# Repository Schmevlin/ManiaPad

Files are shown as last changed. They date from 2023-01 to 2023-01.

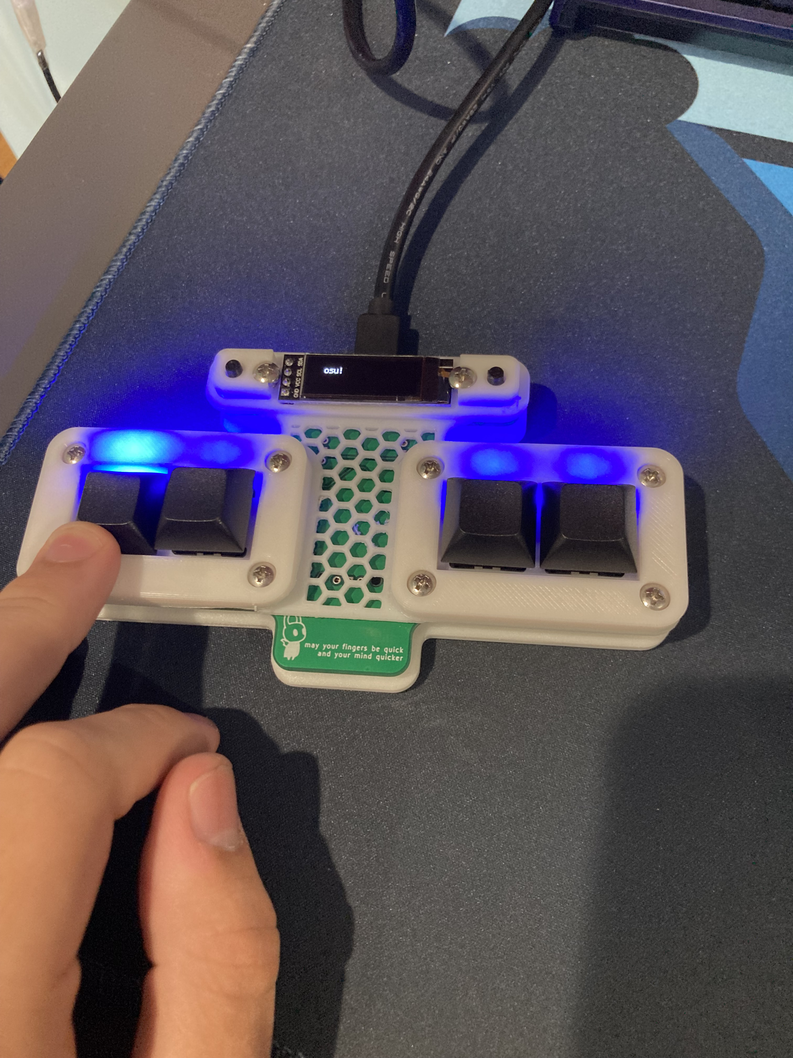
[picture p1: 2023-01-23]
pictures/IMG_0937.jpg

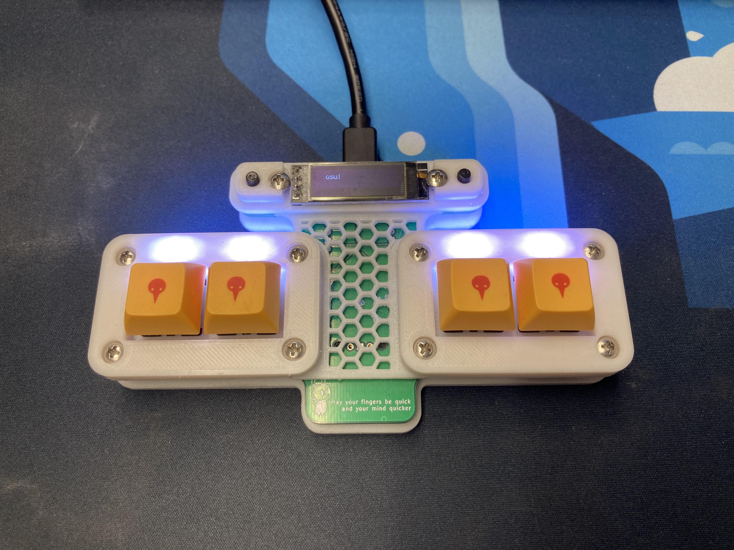
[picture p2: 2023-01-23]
pictures/IMG_2324.jpg

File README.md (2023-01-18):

# ManiaPad
4 button macro pad for use in rhythm games, primarily for osu!/osu!Mania

### Parts List
* pcb based on the one in this repo
* raspberry pi pico
* 0.91" I2C SSD 1306 OLED Module
* 1x4 pin header
* 4 individual WS2812B leds
* (optional) 4 100nF 1206 SMD capacitors
* 4 kailh hotswap sockets
* 4 cherry mx style mechanical keyboard switches
* 2 6mm x 6mm x 4.3mm tactile switch (push button)
* 10 M3 x 16mm machine screws
* 10 M3 nuts
* 3D Printed Parts
  * 4 plate spacer
  * 2 key block
  * 10 button spacer
  * 1 bottom
  * 6 short spacer
  * 1 middle plate
  * 2 button extender

### Button modes/layout
Button modes and layouts are in the code as the "modes" variable, with a tuples of (function name, string name). The functions define what buttons are pressed and what behaviour is associated with each mode. To swap modes hold the top left button then press the top right button.

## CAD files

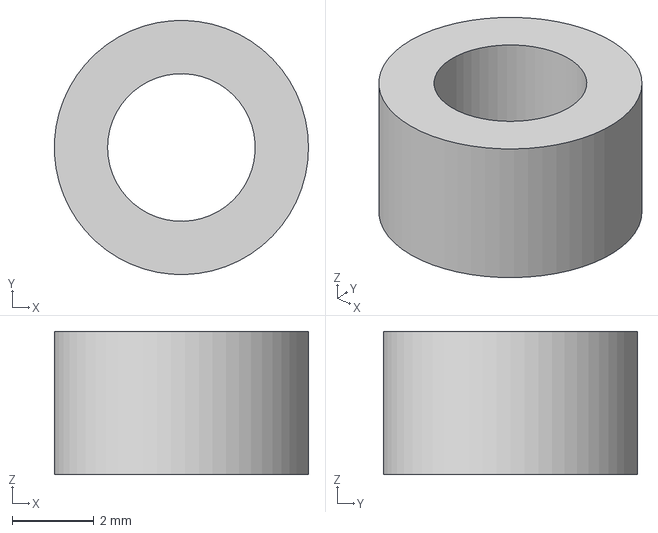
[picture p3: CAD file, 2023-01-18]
cad/plate-spacer.step
6.20 x 6.20 x 3.50 mm

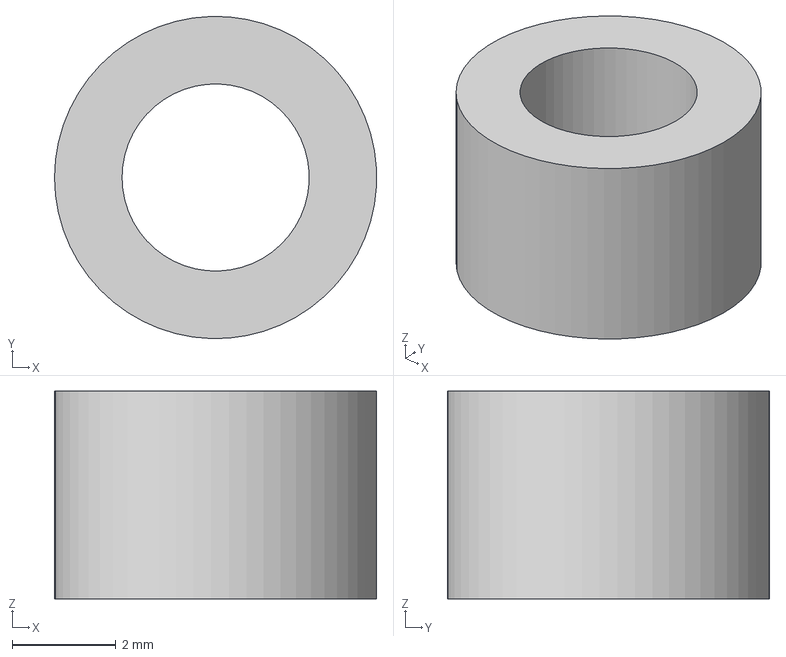
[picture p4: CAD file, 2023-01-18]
cad/bottom-spacer.step
6.20 x 6.20 x 4.00 mm

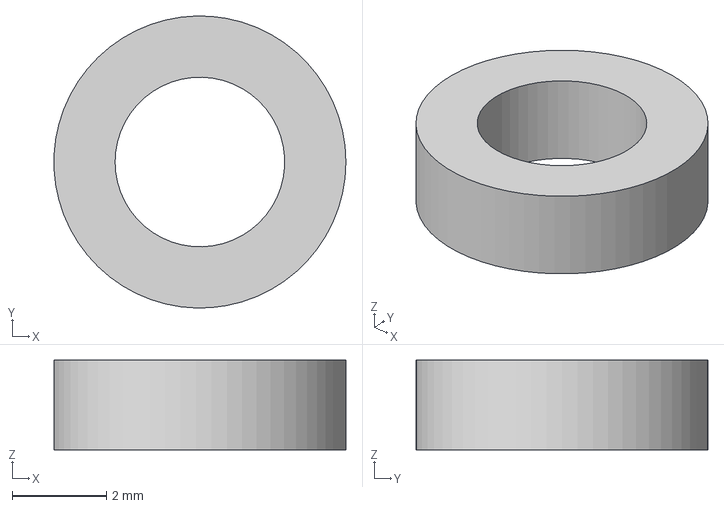
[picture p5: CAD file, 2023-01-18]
cad/short-spacer.step
6.20 x 6.20 x 1.90 mm

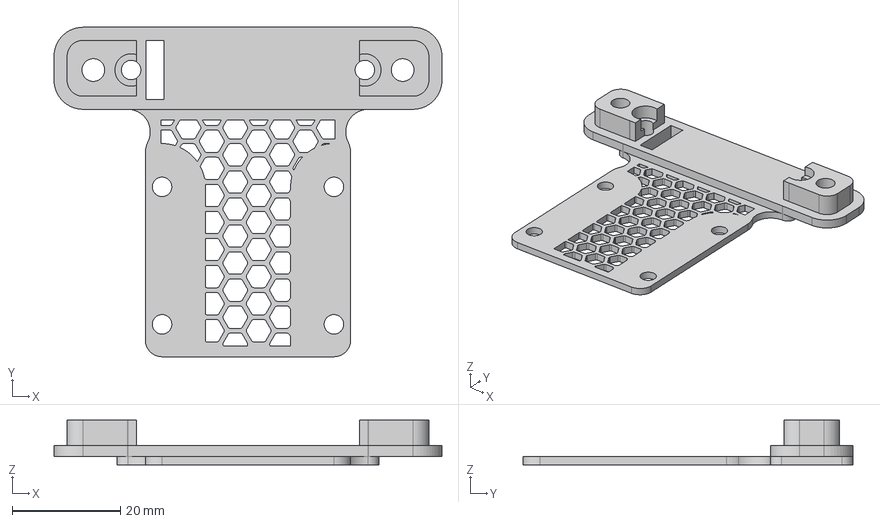
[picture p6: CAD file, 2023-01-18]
cad/middle-plate.step
71.7 x 60.9 x 8.30 mm

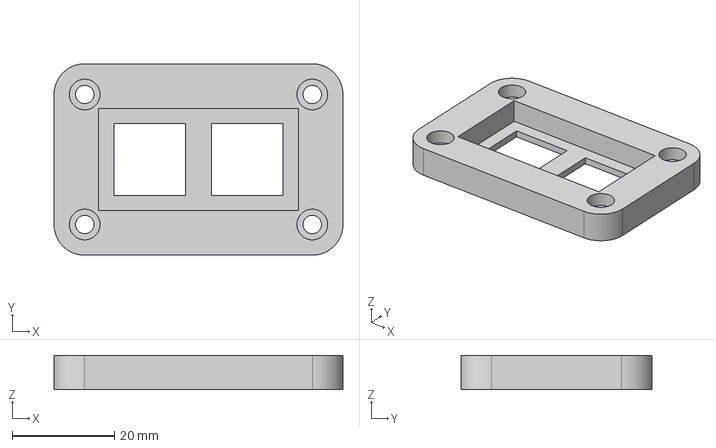
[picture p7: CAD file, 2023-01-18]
cad/key-block.step
56.4 x 37.4 x 6.70 mm

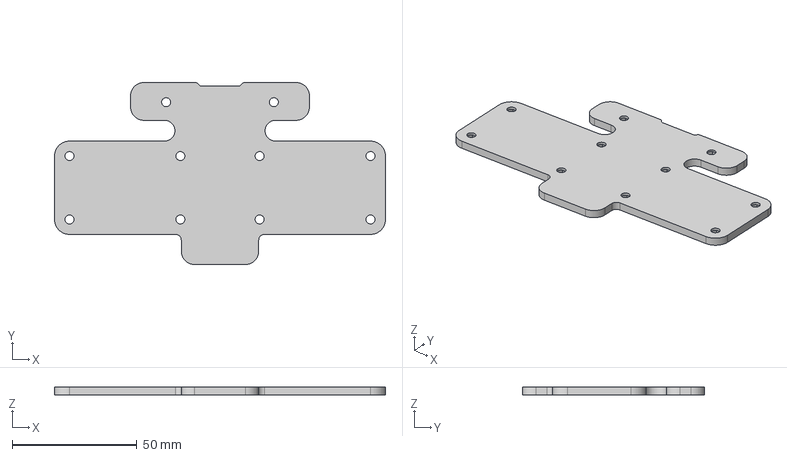
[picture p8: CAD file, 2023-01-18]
cad/bottom.step
132.7 x 73.0 x 3.20 mm

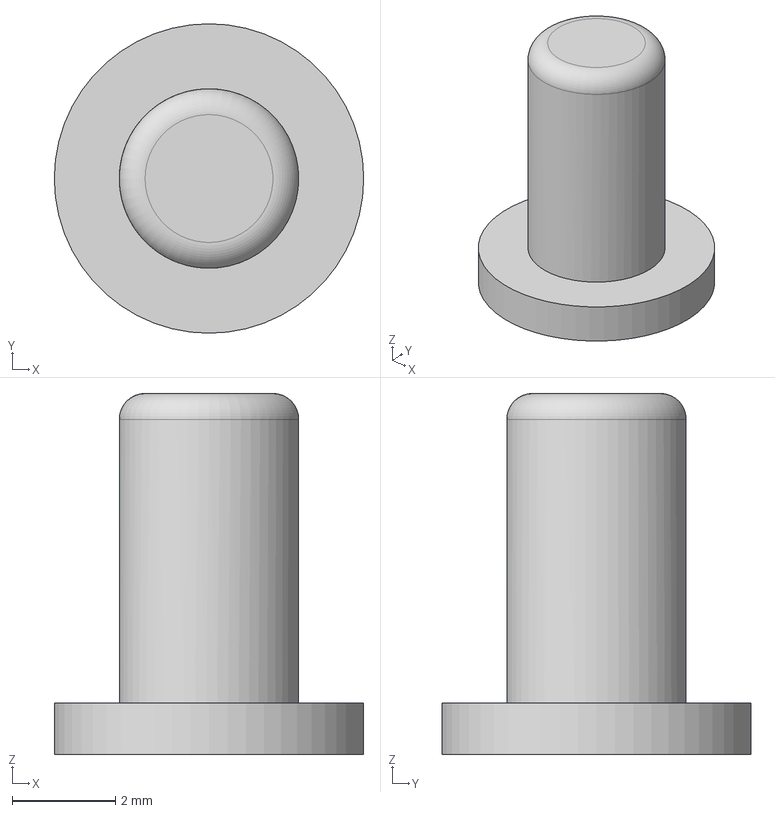
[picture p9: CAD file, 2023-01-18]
cad/button-extender.step
6.00 x 6.00 x 7.00 mm

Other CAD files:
cad/maniaPadRev2 v8.f3z

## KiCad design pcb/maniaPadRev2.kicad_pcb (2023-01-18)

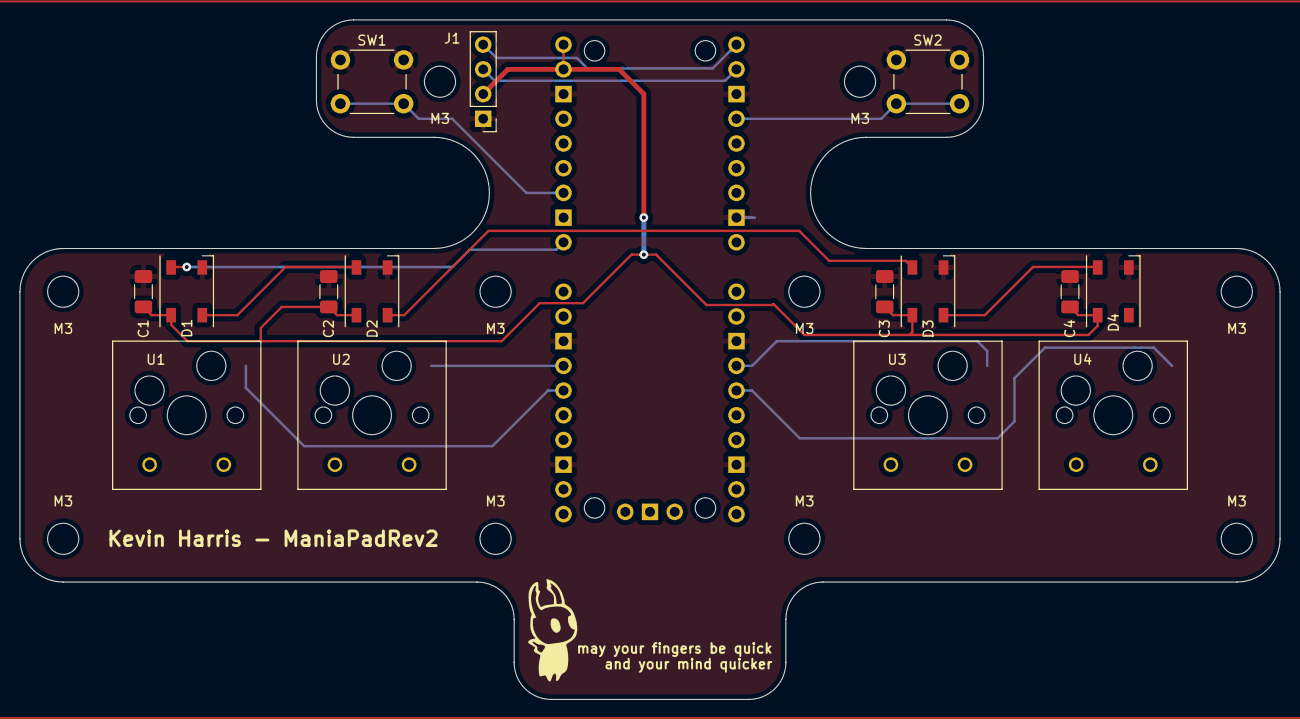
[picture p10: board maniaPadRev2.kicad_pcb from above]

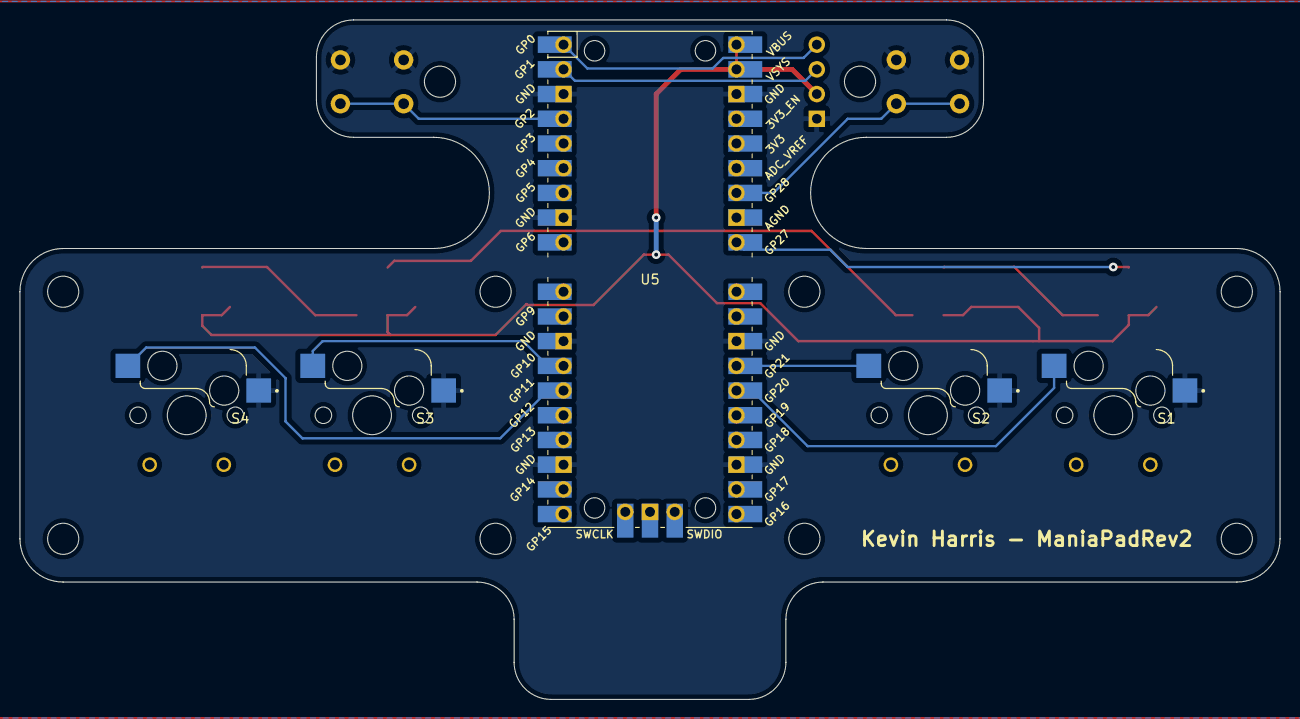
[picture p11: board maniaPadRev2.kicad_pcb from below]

Board: 2 copper layers, 129.5 x 69.8 mm, 30 parts (5 on the bottom side), 14 nets.

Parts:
C1, C2, C3, C4: 100nF; C_1206_3216Metric_Pad1.33x1.80mm_HandSolder
D1, D2, D3, D4: WS2812B; LED_WS2812B_PLCC4_5.0x5.0mm_P3.2mm
J1: Conn_01x04; PinHeader_1x04_P2.54mm_Vertical
M3, M3#2, M3#3, M3#4, M3#5, M3#6, M3#7, M3#8, M3#9, M3#10: MountingHole_3.2mm_M3_ISO7380
S1, S2, S3, S4: PG151101S11; SW_PG151101S11
SW1, SW2: SW_Push; SW_PUSH_6mm
U1, U2, U3, U4: MX1A-11NN; CHERRY_MX1A-11NN_SWITCH
U5: SC0915; RPi_Pico_SMD_TH

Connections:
+5V: C1.2, C2.2, C3.2, C4.2, D1.1 (VDD), D2.1 (VDD), D3.1 (VDD), D4.1 (VDD), J1.2, U5.39 (VSYS), U5.40 (VBUS)
GND: C1.1, C2.1, C3.1, C4.1, D1.3 (VSS), D2.3 (VSS), D3.3 (VSS), D4.3 (VSS), J1.1, S1.1, S2.1, S3.1, S4.1, SW1.1, SW2.1, U5.3 (GND), U5.8 (GND), U5.13 (GND), U5.18 (GND), U5.23 (GND), U5.28 (GND), U5.38 (GND)
unnamed: D1.2 (DOUT), D2.4 (DIN)
unnamed: D1.4 (DIN), U5.32 (GP27)
unnamed: D2.2 (DOUT), D3.4 (DIN)
unnamed: D3.2 (DOUT), D4.4 (DIN)
unnamed: J1.3, U5.2 (GP1)
unnamed: J1.4, U5.1 (GP0)
unnamed: S1.2, U5.26 (GP20)
unnamed: S2.2, U5.27 (GP21)
unnamed: S3.2, U5.14 (GP10)
unnamed: S4.2, U5.15 (GP11)
unnamed: SW1.2, U5.34 (GP28)
unnamed: SW2.2, U5.4 (GP2)

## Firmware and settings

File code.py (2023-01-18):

import time
import board
import digitalio
import neopixel
import usb_hid
from adafruit_hid.keyboard import Keyboard
from adafruit_hid.keycode import Keycode
from adafruit_hid.keyboard_layout_us import KeyboardLayoutUS
from adafruit_hid.consumer_control import ConsumerControl
from adafruit_hid.consumer_control_code import ConsumerControlCode
import displayio
import adafruit_displayio_ssd1306
import adafruit_ssd1306
import busio

#hardware/output setup begin
displayio.release_displays()

i2c = busio.I2C(scl=board.GP1, sda=board.GP0)

display_bus = displayio.I2CDisplay(i2c, device_address = 0x3C)
display_text = adafruit_displayio_ssd1306.SSD1306(display_bus, width=128, height=32)
display = adafruit_ssd1306.SSD1306_I2C(128, 32, i2c)
display.fill(0)
display.show()

keyPins = [board.GP20, board.GP21, board.GP10, board.GP11]
buttonPins = [board.GP28, board.GP2]
ledPin = board.GP27
numLeds = 4

cc = ConsumerControl(usb_hid.devices)
keyboard = Keyboard(usb_hid.devices)
layout = KeyboardLayoutUS(keyboard)

keys = [digitalio.DigitalInOut(pin) for pin in keyPins]                                                                                                            
keys.append(digitalio.DigitalInOut(buttonPins[0]))
#executive decision to make the left button in the key list bc it makes more sense hopefully
button = digitalio.DigitalInOut(buttonPins[1])

for key in keys:
    key.direction = digitalio.Direction.INPUT
    key.pull = digitalio.Pull.UP
button.direction = digitalio.Direction.INPUT
button.pull = digitalio.Pull.UP

pixels = neopixel.NeoPixel(ledPin, numLeds, brightness=1, auto_write=False)
cool_colors = [(255,0,0), (255,255,255)]
for i in range(numLeds):
    pixels[i] = cool_colors[1]

pixels.show()

#setup end

led_should_be_on = True
led_off = False
brightness = 1

#updates is list of 2 index tuple (int index, bool state) passed to most functions

def basic_on_off(updates, colors):
    for update in updates:
        i = update[0] #index
        if i != 4:
            if update[1]: #if pressed
                pixels[i] = colors[0]
            else: #if released
                pixels[i] = colors[1]

def single_color(updates, color):
    basic_on_off(updates, [color, (0,0,0)])

def color(updates) -> None:
    
    if led_should_be_on:
        pixels.fill((1,0,1))
        pass
    elif not led_off:
        pixels.fill((0,0,0))
        led_off = True
    return

def basic_profile(actions, updates):
    for update in updates:
        action = actions[update[0]]
        if isinstance(action, int):
            if update[1]:
                keyboard.press(action)
            else:
                keyboard.release(action)
        elif isinstance(action, list):
            if update[1]:
                keyboard.press(*action)
            else:
                keyboard.release(*action)
        elif isinstance(action, str):
                if update[1]:
                    layout.write(action)

def menu(updates) -> None:
    actions = [Keycode.SHIFT, Keycode.F2, Keycode.ESCAPE, Keycode.ENTER, 'mode=m keys=4']
    basic_profile(actions, updates)
    
def osu(updates) -> None:
    actions = [Keycode.S, Keycode.D, [Keycode.F, Keycode.SHIFT], Keycode.TAB, Keycode.SPACE]
    basic_profile(actions, updates)

def mania(updates) -> None:
    actions = [Keycode.D, Keycode.F, Keycode.J, Keycode.K, Keycode.GRAVE_ACCENT]
    basic_profile(actions, updates)

def multimedia(updates) -> None:
    actions = [ConsumerControlCode.SCAN_PREVIOUS_TRACK, ConsumerControlCode.SCAN_NEXT_TRACK, ConsumerControlCode.PLAY_PAUSE, Keycode.PAUSE, [Keycode.CONTROL, Keycode.SHIFT, Keycode.ALT, Keycode.M]]
    #didnt want to include the consumer code stuff in basic_profile because both those and keycodes are just ints and i didnt know how to differentiate them well
    for update in updates:
        action = actions[update[0]]
        if update[0] != 3 and update[0] != 4:
            if update[1]:
                cc.send(action)
        elif isinstance(action, int):
            if update[1]:
                keyboard.press(action)
            else:
                keyboard.release(action)
        elif isinstance(action, list):
            if update[1]:
                keyboard.press(*action)
            else:
                keyboard.release(*action)

FAKE_MODES = 1 #modes that shouldnt be toggleable and should go at the end of the list
modes = [(osu, 'osu!'), (mania, 'osu!Mania'), (multimedia, 'Multimedia'), (menu, 'Song Browser')]
mode = 0
realMode = mode #mode index ignoring if youre on song browser
print(modes[mode][1])

keyStates = [0 for _ in range(len(keys))]
lastKeyStates = list(keyStates)
buttonState = 0
lastButtonState = buttonState
rgb_updated = False

buttonPressed = False
modeToggled = False

while True:
    #find current button states
    for i in range(len(keys)):
        keyStates[i] = not keys[i].value
    buttonState = not button.value

    if buttonState != lastButtonState:
        if buttonState:
            buttonPressed = True
        else:
            buttonPressed = False
            if not modeToggled:
                if mode != -1:
                    mode = -1
                else:
                    mode = realMode
                print()
                print(modes[mode][1])
            modeToggled = False  
                
    #updates is list of 2 index tuple (int index, bool state) passed to most functions
    updates=[]

    for i in range(len(keys)):
        if keyStates[i] != lastKeyStates[i]:
            rgb_updated = True
            if keyStates[i]:
                updates.append((i, True))
            else:
                updates.append((i, False))
    
    if buttonPressed:
        if keyStates[-1] != lastKeyStates[-1] and keyStates[-1]:
            mode = (mode+1)%(len(modes) - FAKE_MODES)
            realMode = mode
            print()
            print(modes[mode][1])
            updates.pop(-1)
            modeToggled = True

    basic_on_off(updates, cool_colors)
    #single_color(updates, (255,0,100))
    modes[mode][0](updates)

    lastKeyStates = list(keyStates)
    lastButtonState = buttonState

    if rgb_updated: pixels.show()
    time.sleep(.01)
